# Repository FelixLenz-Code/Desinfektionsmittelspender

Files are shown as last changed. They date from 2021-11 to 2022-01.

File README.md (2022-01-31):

# Smarter Desinfektionsmittelspender
#### [Homeassistant](https://www.home-assistant.io/ "Homeassistant") & [ESPHome](https://esphome.io/ "ESPHome")
Ein smarter Desinfektionsmittelspender, der sowohl kontaktlos funktioniert als auch mit Benachrichtigungsfunktionen über Füllstand und Nutzung ausgestattet ist, soll entwickelt werden. 
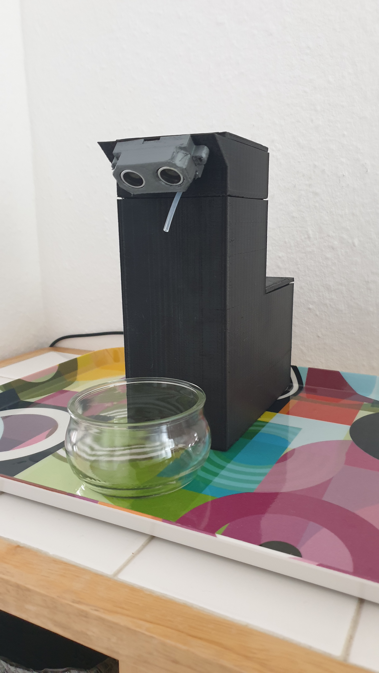
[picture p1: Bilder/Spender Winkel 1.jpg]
Bild Spender


## Hardware
Der Arduino Nano steuert die Pumpe vollkommen autonom mithilfe des Ultraschallsensors (HC-SR04). Auch gibt er, dem mit dem WLAN verbundenen zweiten Mikrocontroller (NodeMCU bzw. ESP8266) weiter, dass der Spender benutzt wurde. Dies geschieht über ein Relais, da der Arduino mit 5V und der NodeMCU mit 3,3V arbeitet. Der NodeMCU ist außerdem mit einem Füllstandssensor ausgestattet. Der NodeMCU ist ein WLAN Entwicklerboard, ausgestattet mit einem ESP8266 Chip von Espressif, welcher auch oft in Smarthomegeräten wiederzufinden ist. Um alles mit Strom zu versorgen verbinden wir die Stromversorgung mittels Pins beider Microcontroller miteinander. Dann muss man nur noch den Arduino Nano mit Strom über USB versorgen und schon läuft alles. (Die restliche Verschaltung kann der Zeichnung entnommen werden.)

Teileliste:
- NodeMCU v2
- Arduino Nano
- HC-SR04 Ultraschallsensor
- Wasserstandssensor 
- 2 Relais (FRS1B-S)
- 5V oder 12V Pumpe (Ich benutze eine Bioengeneering Pumpe)
- Passender Schlauch (1m reicht)
- Prototyping Board (72x72mm)
- Pinheader (Male & Female)
- Female Jumper Kabel
- Litze zur Verlängerung der Jumper Kabel und fürs Boad
- Home Assistant Server mit ESPhome
- Arduino IDE
- USB Kabel (micro und mini)
- PC zum programmieren
- 3D Drucker oder Druckdienst für das Gehäuse 

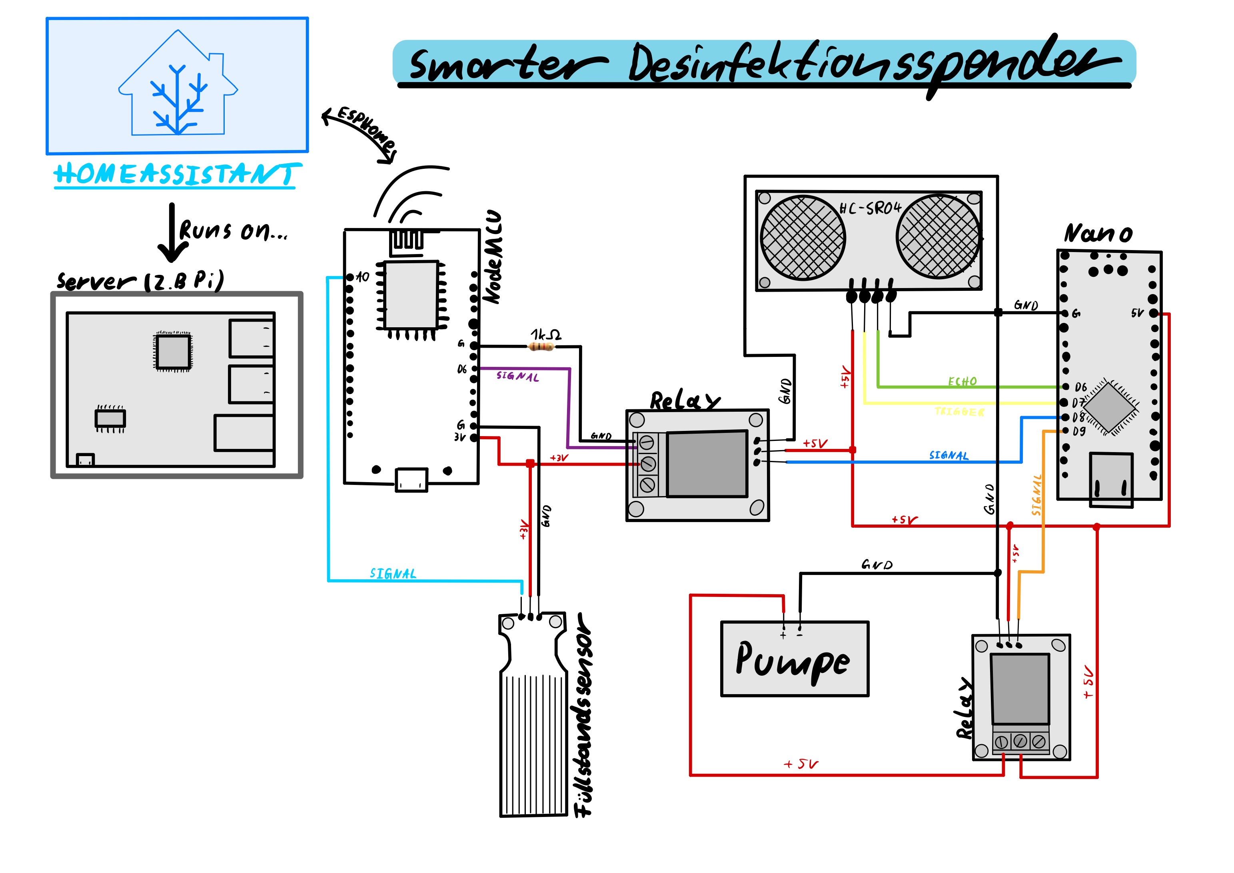
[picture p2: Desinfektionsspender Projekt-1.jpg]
Zeichnung

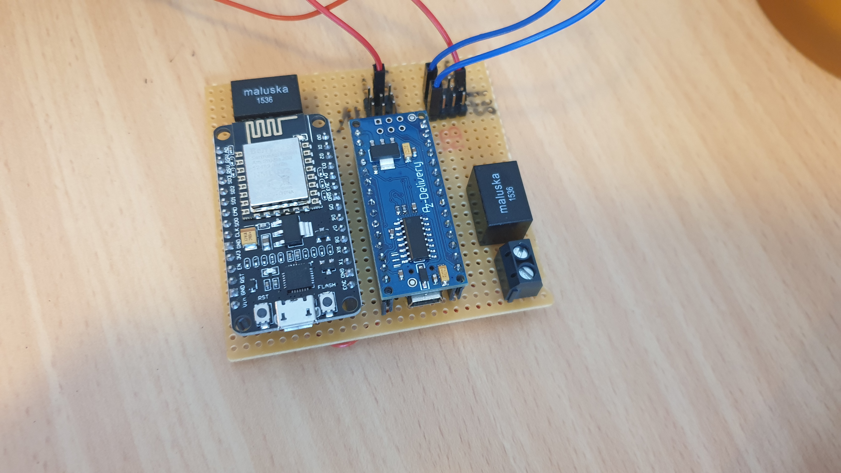
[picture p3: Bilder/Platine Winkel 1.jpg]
Platine


## Software
Der NodeMCU wird mit der Software von ESPHome geflashed. Diese Software kann dann in einem lokalen Netzwerk mit einem Homeassistant Server kommunizieren und Daten wie Füllstand der Desinfektionsmittelflasche, als auch die Häufigkeit der Benutzung übertragen. In Homeassistant selber kann dann mit den Daten einiges umgesetzt werden. So kann man z.B. Benachrichtigungen verschicken wenn ein Spender bald leer wird. Auch lassen sich andere Aktoren triggern. Wie z.B. LEDs, SmartHome Lampen oder Steckdosen. Hier sind kaum Grenzen gesetzt. (Voraussetzung dafür ist eine Homeassistant Installation mit ESPHome Addon.)

Auch kann man sich genaue Daten, in Form von Zahlen und Graphen, anzeigen lassen und auswerten. Z.B. welcher Spender wird am meisten genutzt? Wie viel Kosten hat man durchschnittlich im Monat? Wie oft muss Desinfektionsmittel nachgefüllt werden? Das alles kann man sich anzeigen lassen. 

HA Info

## Gehäuse
Das Ganze wird dann noch in eine schönes 3D gedrucktes Gehäuse gepackt und schon hat man seinen smarten Desinfektionsmittelspender. Die Dateien können hier aus Github oder aus [Thingiverse](https://www.thingiverse.com/thing:5225847) heruntergeladen werden.
Das Hauptteil und der Aufsatz müssen mit Support gedruckt werden! Ich habe in PLA mit 20% Infill gedruckt. 
Der Deckel wird 2x benötigt!
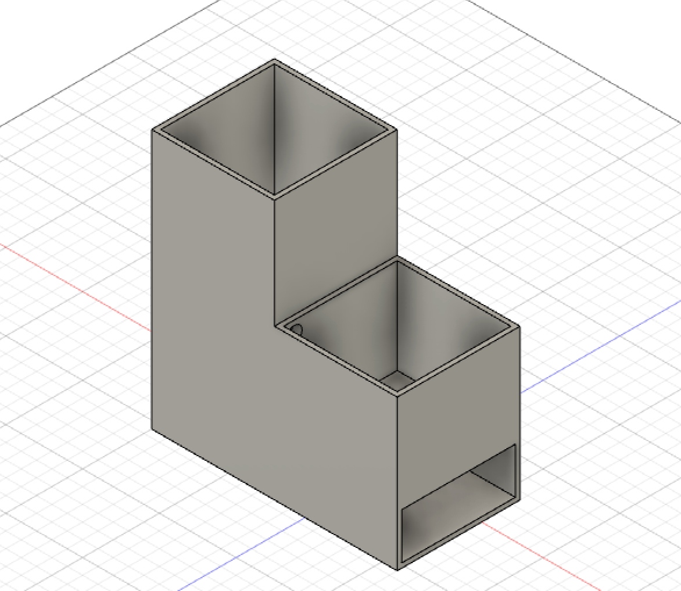
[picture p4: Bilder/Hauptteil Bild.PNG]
3D Zeichnung Hauptteil


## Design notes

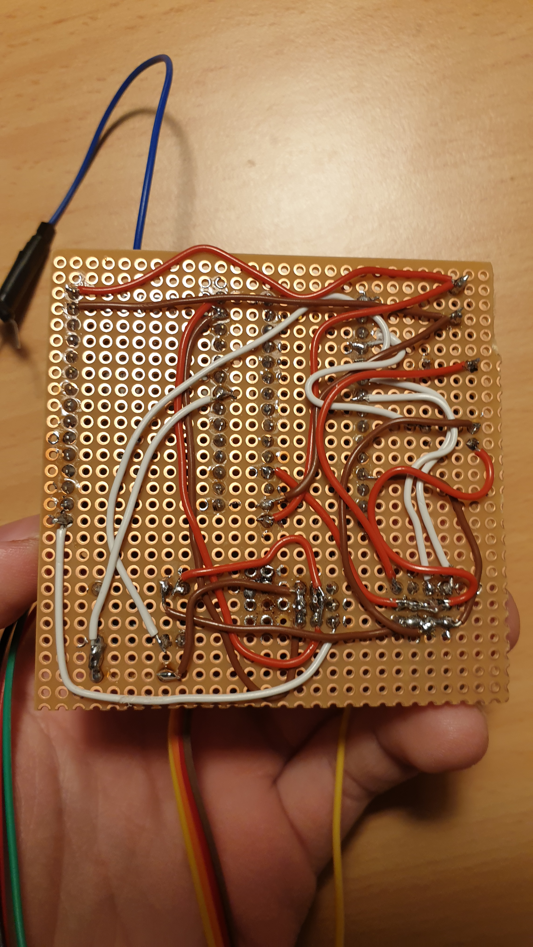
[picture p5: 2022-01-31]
Bilder/Platine Winkel 2.jpg

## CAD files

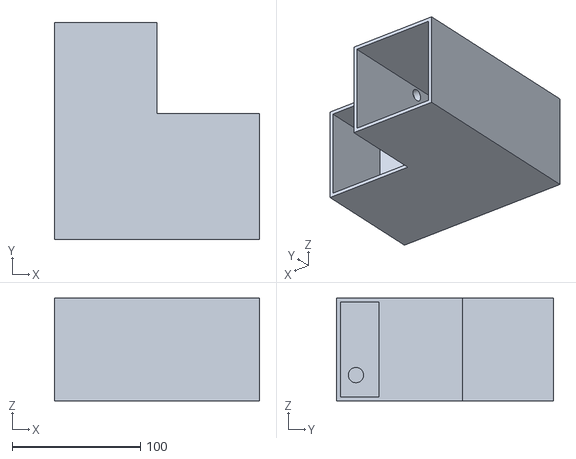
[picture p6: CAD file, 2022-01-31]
3D Files Gehäuse/Hauptteil Desinfektionsmittelspender.stl
160.0 x 169.0 x 80.0

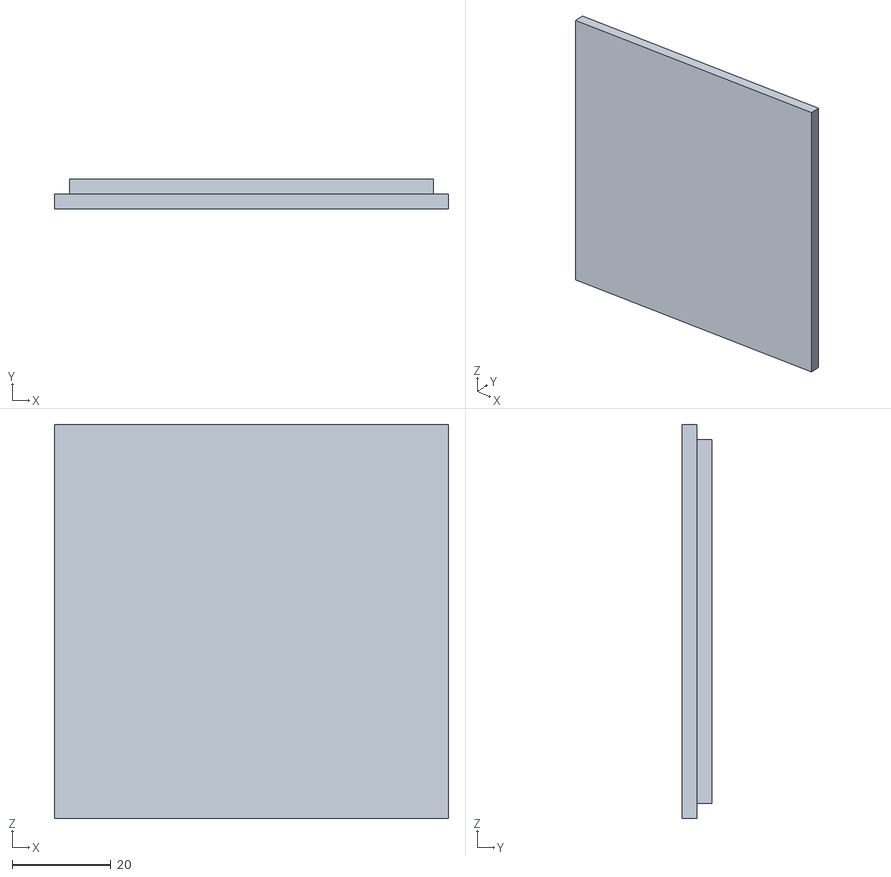
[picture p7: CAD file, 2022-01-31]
3D Files Gehäuse/Deckel Desinfektionsmittelspender.stl
80.0 x 6.00 x 80.0

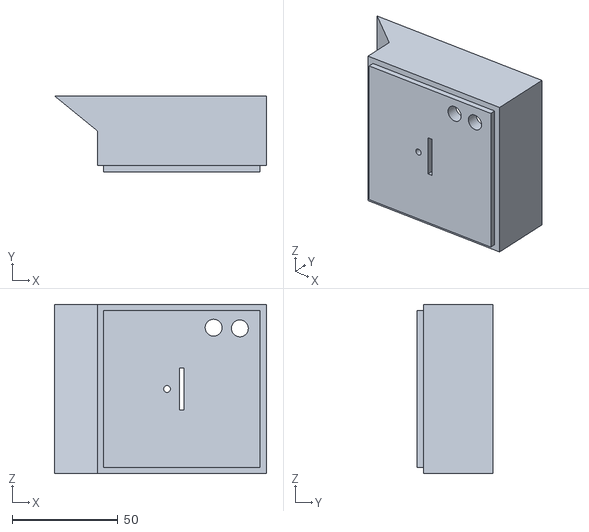
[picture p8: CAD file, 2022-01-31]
3D Files Gehäuse/Aufsatz Desinfektionsmittelspender.stl
100.2 x 36.0 x 80.0

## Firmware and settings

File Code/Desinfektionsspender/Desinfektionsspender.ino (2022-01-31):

//Ultraschallsensor
int trigger=7; 
int echo=6; 
long dauer=0; 
long entfernung=0; 

//Pumpe
int Pumpe=9;

//Benachrichtigung 
int Benachrichtigung = 8;

void setup()
{
//Ultraschallsensor         
pinMode(trigger, OUTPUT); 
pinMode(echo, INPUT);

//Pumpe
pinMode(Pumpe, OUTPUT);

//Benachrichtigung
pinMode(Benachrichtigung, OUTPUT);

}
void loop()
{

//Messvorgang
digitalWrite(trigger, LOW); 
delay(5); 
digitalWrite(trigger, HIGH); 
delay(10);
digitalWrite(trigger, LOW);
dauer = pulseIn(echo, HIGH); 
entfernung = (dauer/2) * 0.03432; 

if(entfernung <= 6 && entfernung > 1) {

    digitalWrite(Pumpe, HIGH);
    delay(5000);
    digitalWrite(Pumpe, LOW);  

}
//Ausgabe(Umsetzung)
if(entfernung <= 6 && entfernung > 1) {

    digitalWrite(Benachrichtigung, HIGH);
    delay(800);
    digitalWrite(Benachrichtigung, LOW);

}

delay(4000);   
}

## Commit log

2021-11-05 Neue Zeichung + Relais
    Ein weiteres Relais wurde dem ganzen hinzugefügt um die Pumpe benutzen zu können
2022-01-31 3D files
    [Aufsatz Desinfektionsmittelspender.stl, Deckel Desinfektionsmittelspender.stl, Hauptteil Desinfektionsmittelspender.stl]
